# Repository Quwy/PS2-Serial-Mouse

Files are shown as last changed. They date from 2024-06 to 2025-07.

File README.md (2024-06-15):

# PS/2 to Serial mouse adapter
Active adapter for connect PS/2 mouse to the RS232C serial port.

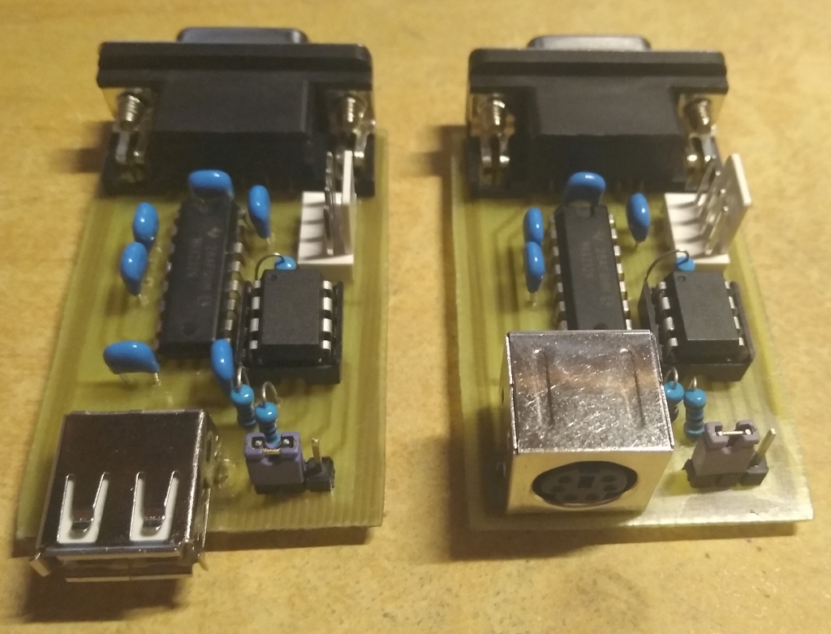
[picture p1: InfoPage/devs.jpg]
Adapters photo


With this adapter you don't need to search and buy rare and expensive old serial mouse for your retro computer. Any mouse with PS/2 interface and most of simple USB-mouses will operate as Microsoft or Logitech serial mouse.

* Only 16 parts including PCB and sockets.
* Small device size.
* Simple one-layer one-side PCB.
* No SMD components.
* Common and cheap microcontroller.
* Selectable 3-button mouse protocol (Microsoft or Logitech).
* Open-source electronics and firmware.

Adapter is based on ATtiny25 microcontroller, but PCB layout and firmware source are fully compatible with whole 25/45/85 series without any changes.

There are two variants of PCB layout: with PS/2 and USB mouse socket. Both they have one-layer one-side design without VIA covering and fully ready even for manual tracing.

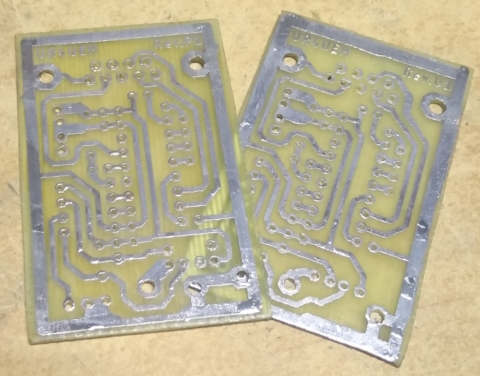
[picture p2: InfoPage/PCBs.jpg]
PCBs


They are fully identical except an mouse socket type.

Note what USB version does not provide true USB host. The USB socket is only used as built-in PS/2-to-USB passive adapter.

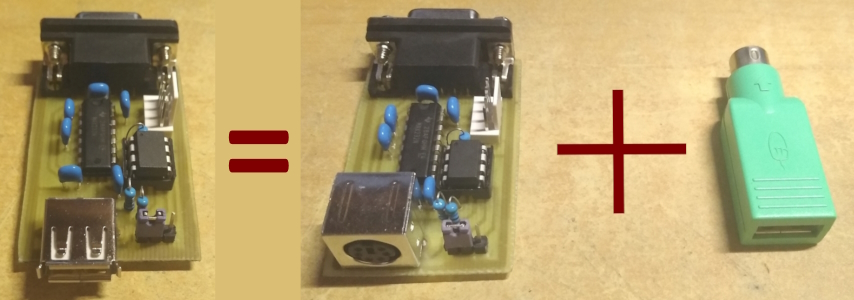
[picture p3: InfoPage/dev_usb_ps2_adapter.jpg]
USB Adapter


Only universal USB+PS/2 mouse will work!

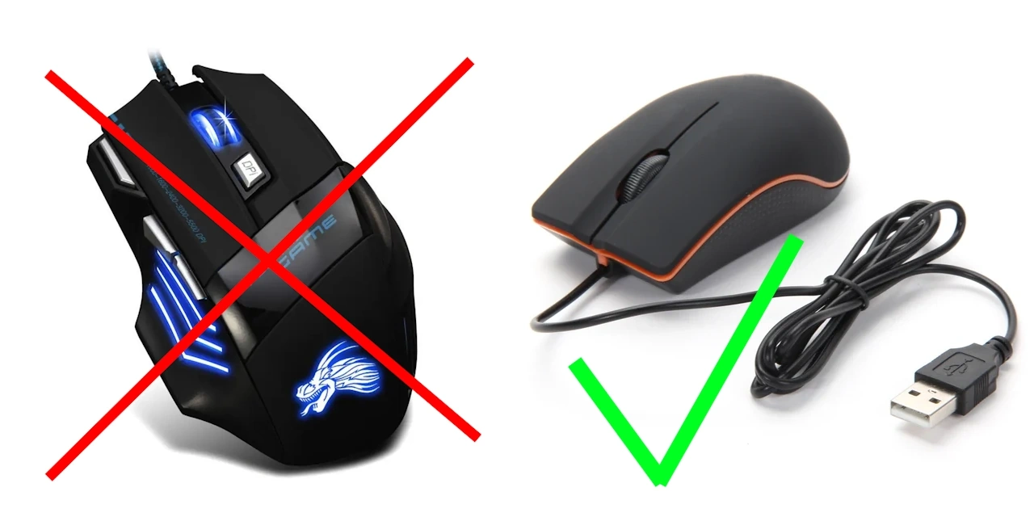
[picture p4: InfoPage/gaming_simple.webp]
Gaming VS Simple


Usually it is a simple office mouse with two buttons and one clickable wheel.

Jumper is used to switch 3-button mouse protocol extensions between Microsoft and Logitech style. The 1-2 position (close to the mouse socket) mean Microsoft, 2-3 respectively Logitech. Jumper is hotplug-ready.

Since RS232C port does not provide power supply enough to feed most of PS/2 mouses, the standart "floppy-style" 4-pin MOLEX plug is used as power source (+5V line only).

Please see also [README of schematic diagramm](https://github.com/Quwy/PS2-Serial-Mouse/blob/main/Electronix/README.md) and [README of firmware section](https://github.com/Quwy/PS2-Serial-Mouse/blob/main/Firmware/README.md).

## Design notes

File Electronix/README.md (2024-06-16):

# PS2 to Serial mouse adapter electronics

Schematic diagrams and PCB layouts for both PS/2 and USB adapter variants.

## PS/2 socket

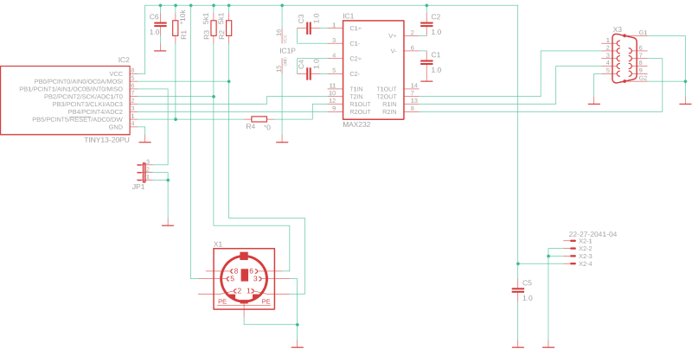
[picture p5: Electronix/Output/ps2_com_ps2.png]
PS/2 Diagramm


## USB socket

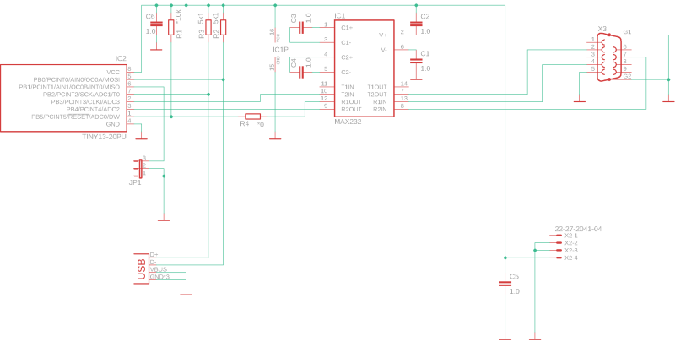
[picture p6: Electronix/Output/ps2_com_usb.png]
USB Diagramm


## Differences between RTS-only and RTS+DTR implementations.

**RTS-only** implementation listen only RTS line of the RS232C port to detect init/reset signal from the mouse driver. The DTR line is ignored. This mean not full compliance with Serial Mouse specs, but enough for most existing mouse drivers. But it does give an opportunity to preserve pin 1 of microcontroller as default RESET function and use simple and cheap ISP programmers (such as [USBASP](https://www.google.com/search?q=usbasp)) to flash IC.

In this mode resistor R4 must **NOT** be installed on PCB, and there is recommended to install resistor R1 as RESET pull-up.

**RTS+DTR** implementation as opposed to RTS-only listen both RTS and DTR signals and will compatible with any mouse driver. But this is achieved at the cost of switching pin 1 to GPIO mode and lose microcontroller's ISP function. Since fuses will flashed, only high voltage serial programming tool can be used to write the IC (including reset fuses to default state). So be very careful with fuses for RTS-DTR mode.

For RTS+DTR mode resistor R4 (0-10 Ohm or jumper wire) must be installed to PCB and R1 must **NOT** be installed.

Everything else is same in both modes.

## PCB layout features

In the both PS/2 and USB layouts socket shield is used as signal ground trace for connect mouse GND pin to adapter ground. For this reason only metal sockets must be used. Especially it concerns a PS/2 which wide available in the whole-plastic variant without an metal shield.

## PCB renders and Gerber files
https://github.com/Quwy/PS2-Serial-Mouse/tree/main/Electronix/Output

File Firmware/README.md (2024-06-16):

# PS2 to Serial mouse adapter Firmware

This folder contain Firmware sources for the adapter.

To build please use Microchip Studio 7.0 or later with AVR/GNU C Compiler 7.3.0 or more modern. Previous versions of compiler can reach microcontroller's flash size.

Please see [Defines.h](https://github.com/Quwy/PS2-Serial-Mouse/blob/main/Firmware/Defines.h) file for build options before make.

## FUSES

About differences between RTS-only and RTS+DTR implementations please see [electronics section](https://github.com/Quwy/PS2-Serial-Mouse/blob/main/Electronix/README.md).

### RTS-only fuses
```
efuse 0x01
lfuse 0xc1
hfuse 0xdf
```

### RTS+DTR fuses
```
efuse 0x01
lfuse 0xc1
hfuse 0x7f
```

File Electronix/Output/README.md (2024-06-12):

# PS2 to Serial mouse adapter PCB renders

Folder for PCB prerenders and Gerber files

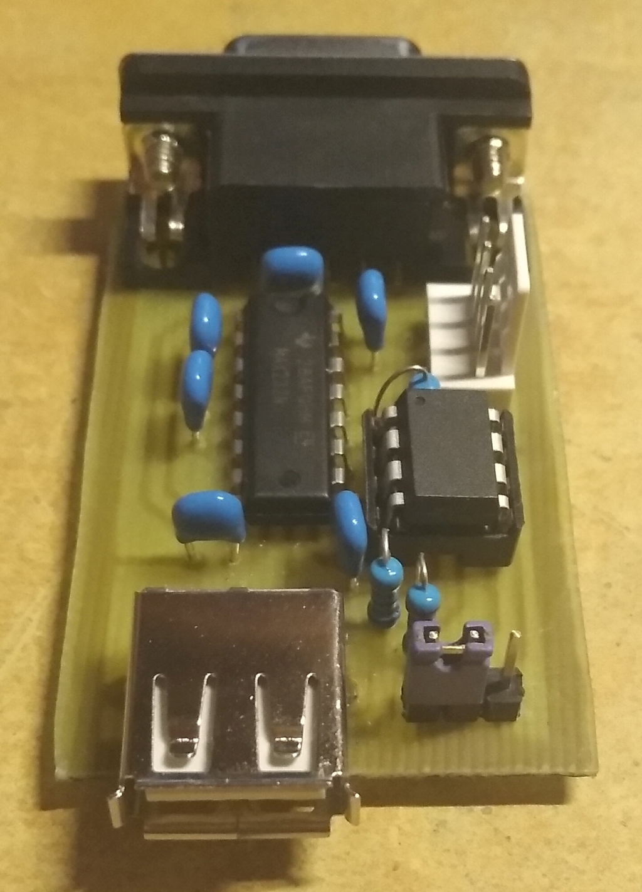
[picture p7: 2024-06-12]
InfoPage/dev_usb.jpg

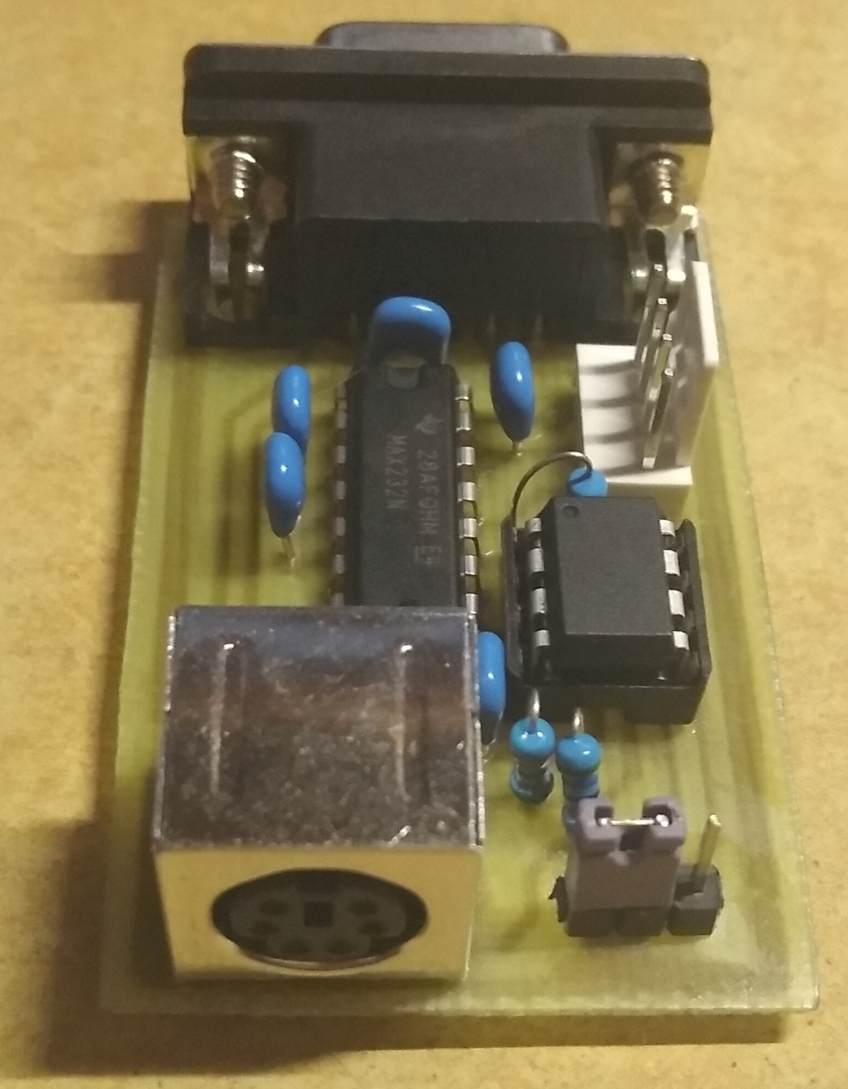
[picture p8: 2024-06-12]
InfoPage/dev_ps2.jpg

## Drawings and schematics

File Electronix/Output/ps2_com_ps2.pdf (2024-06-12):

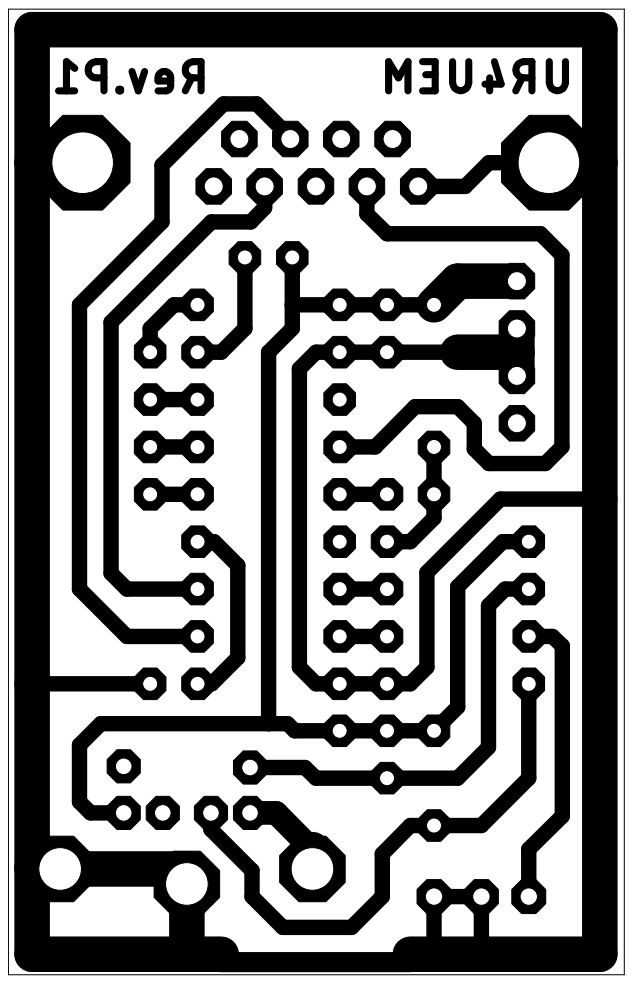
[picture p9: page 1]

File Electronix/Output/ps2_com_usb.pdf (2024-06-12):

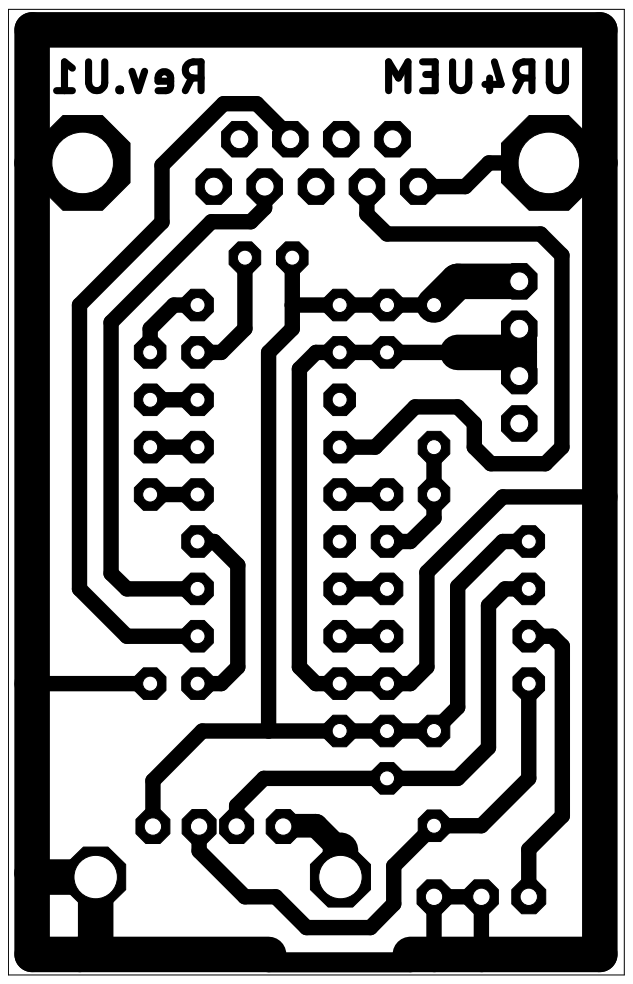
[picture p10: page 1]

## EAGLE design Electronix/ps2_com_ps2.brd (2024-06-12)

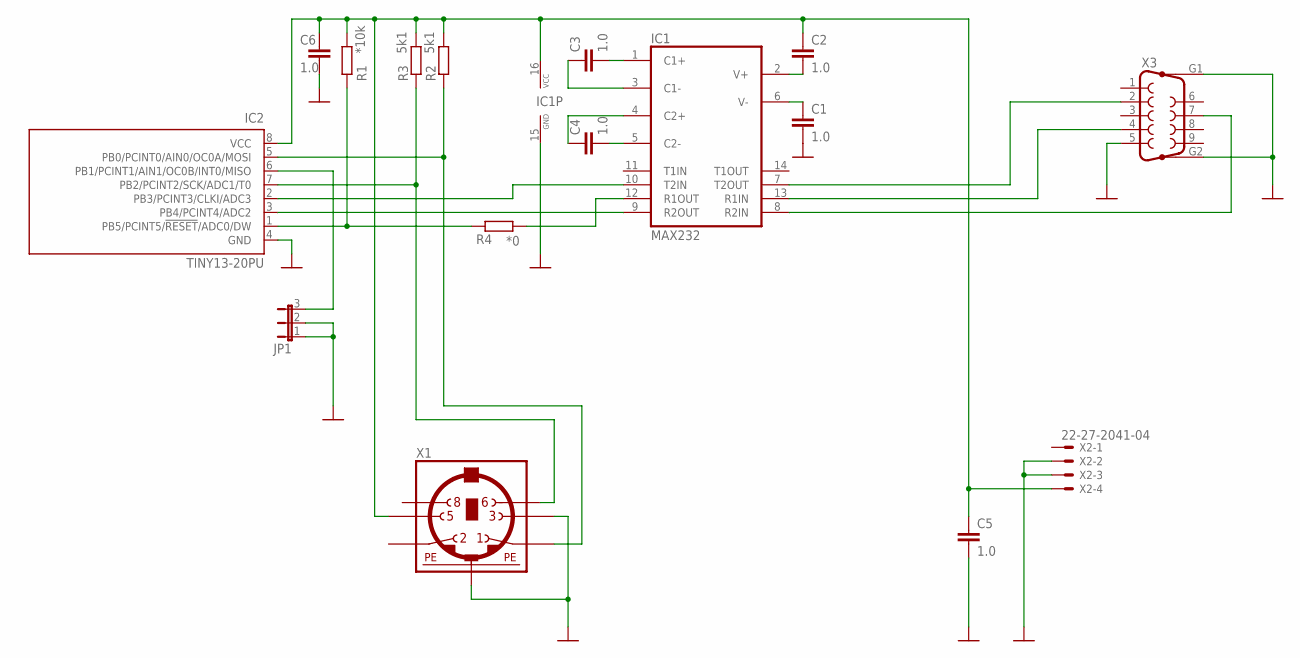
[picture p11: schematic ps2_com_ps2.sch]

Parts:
C1, C2, C3, C4, C5, C6: 1.0; C025-025X050
IC1: MAX232; DIL16
IC2: TINY13-20PU; DIL08
JP1: JP2E; JP2
R1: *10k; 0204/7
R2: 5k1; 0204/5
R3: 5k1; 0204V
R4: *0; 0204V
X1: MINI_DIN_6; M_DIN6
X2: 22-27-2041-04; 6410-04
X3: F09HP

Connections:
CLOCK: IC2.7 (PB2/PCINT2/SCK/ADC1/T0), R3.1, X1.6
DATA: IC2.5 (PB0/PCINT0/AIN0/OC0A/MOSI), R2.1, X1.1
DTR: IC1.13 (R1IN), X3.4
GND: C1.2, C5.2, C6.2, IC1.15 (GND), IC2.4 (GND), JP1.1, JP1.2, X1.3, X1.SH1 (PE1), X1.SH2 (PE1), X1.SH3 (PE1), X2.2, X2.3, X3.5, X3.G1, X3.G2
unnamed: C4.2, IC1.5 (C2-)
unnamed: C4.1, IC1.4 (C2+)
unnamed: C3.1, IC1.3 (C1-)
unnamed: C3.2, IC1.1 (C1+)
unnamed: C1.1, IC1.6 (V-)
unnamed: C2.2, IC1.2 (V+)
unnamed: IC2.6 (PB1/PCINT1/AIN1/OC0B/INT0/MISO), JP1.3
unnamed: IC1.12 (R1OUT), R4.1
RTS: IC1.8 (R2IN), X3.7
RXD: IC1.7 (T2OUT), X3.2
TTL_DTR: IC2.1 (PB5/PCINT5/!RESET!/ADC0/DW), R1.1, R4.2
TTL_RTS: IC1.9 (R2OUT), IC2.3 (PB4/PCINT4/ADC2)
TTL_RXD: IC1.10 (T2IN), IC2.2 (PB3/PCINT3/CLKI/ADC3)
VCC: C2.1, C5.1, C6.1, IC1.16 (VCC), IC2.8 (VCC), R1.2, R2.2, R3.2, X1.5, X2.4

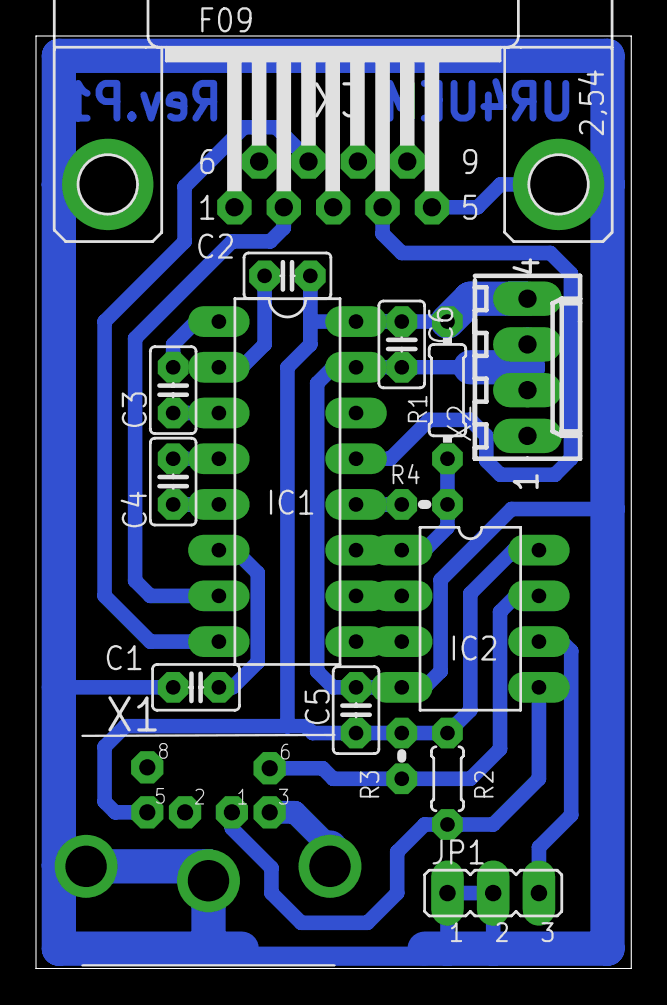
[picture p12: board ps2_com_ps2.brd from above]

Board: 2 copper layers, 33.1 x 51.8 mm, 16 parts (0 on the bottom side), 18 nets.

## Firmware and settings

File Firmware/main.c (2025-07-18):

/*
 * main.c
 *
 * Main module
 * 
 * Author: Mike Cherkes, UR4UEM
 *
 */ 

#include "Defines.h"

#include <avr/io.h>
#include <avr/interrupt.h>
#include <avr/sleep.h>
#include <avr/wdt.h>
#include <stdint.h>
#include <stdbool.h>

#if defined(START_MARKER)
#include <util/delay.h>
#endif

#include "PS2_mouse.h"
#include "UART_mouse.h"

#define INITIAL_PINB ((1 << PB0) | (1 << PB2) | (1 << PB4)) // initial state of pins on PORTB (initial value assumes high levels on the SDA ans SCL as bus idle state, high on RTS as no terminal connected)

typedef enum {
    TERMINAL_STATE_INACTIVE,
    TERMINAL_STATE_PENDING,
    TERMINAL_STATE_ACTIVE
} terminal_state_t;

static volatile terminal_state_t terminal_state;
static volatile bool terminal_tx_ext_id = false;

// init watchdog
static inline void wdt_init(void) {
    WDTCR = (1 << WDCE) | (1 << WDE); // watchdog preparing
    WDTCR = (1 << WDIE) | WDTO_60MS; // setup watchdog to interrupt mode every 60 ms
}

// init GPIO system
static inline void gpio_init(void) {
    
    #ifdef START_MARKER // start marker for logic analizer trigger
    DDRB |= (1 << DDB3);
    _delay_us(10);
    DDRB &= ~(1 << DDB3);
    #endif

    GIMSK |= (1 << PCIE); // Enable pin changes interrupt
}

// init MCU
static inline void mcu_init(void) {
    sleep_enable(); // prepare sleep mode
    set_sleep_mode(SLEEP_MODE_IDLE); // SLEEP_MODE_IDLE allows to handle all necessary events
    sei(); // enable interrupts

    #ifdef PROTEUS // Proteus incorrectly simulates PLL clock (set 64 MHz instead of 16 MHz)
    CLKPR |= (1 << CLKPCE); // enable system clock prescaler
    CLKPR = (1 << CLKPS1);  // set prescaler for /4
    #endif
}

// pin change event local handler
static inline void main_PCINT0(const uint8_t prev_PINB) {
    if(uart_host_active(prev_PINB) && !uart_host_active(PINB)) { // if terminal ready pins changed state from "ready" to "not ready"
        switch(terminal_state) {
            case TERMINAL_STATE_ACTIVE: // if terminal was active, stopping all and deactivate terminal state
                uart_mouse_stop();
                ps2_mouse_stop(); // reset mouse and stop PS2 communication
                terminal_tx_ext_id = false;
                terminal_state = TERMINAL_STATE_INACTIVE;
                break;

            case TERMINAL_STATE_PENDING: // if terminal in pending state, just reset state to inactive
                terminal_state = TERMINAL_STATE_INACTIVE;
                break;

            default: // nothing to do if terminal already inactive
                break;
        }
    }
}

// perform periodic checks and tasks
static inline void main_timer_process(void) {
    switch(terminal_state) {
        case TERMINAL_STATE_PENDING: // if terminal state remains pending whole WDT timer delay, set terminal ready state
            terminal_state = TERMINAL_STATE_ACTIVE;
            ps2_mouse_start(); // init PS/2 mouse and start communication
            break;

        case TERMINAL_STATE_INACTIVE: // if terminal state is inactive
            if(uart_host_active(PINB)) { // check pins
                terminal_state = TERMINAL_STATE_PENDING; // set sdtate to pending if pins in the active state
            }
            break;

        default: // if terminal is active or unknown state, do nothing
            break;
    }

    if(terminal_tx_ext_id && terminal_state == TERMINAL_STATE_ACTIVE) {
        uart_mouse_tx_ext_id(); // send extended id if terminal is active and primary id already sent
        terminal_tx_ext_id = false;
    }
}


// main function
int main(void) {
    const ps2_mouse_state_t *ps2_mouse_state;
    
    gpio_init();
    mcu_init();
    uart_mouse_init();
    ps2_mouse_init(&ps2_mouse_state); // init PS2 mouse and get mouse data pointer
    wdt_init();
    
    #ifndef DUMMY_TEST_MODE

    terminal_state = (uart_host_active(PINB) ? TERMINAL_STATE_PENDING : TERMINAL_STATE_INACTIVE); // initial terminal state

    // main event loop
    while(true) {
        sleep_cpu(); // always try to avoid free-running main loop, use sleep mode if no current tasks

        ps2_mouse_process(terminal_state != TERMINAL_STATE_ACTIVE); // process mouse events if PC terminal is active
        
        if(ps2_mouse_responce_ok()) { // if init mouse response is "OK"
            uart_mouse_tx_id(); // send primary mouse id to port
            terminal_tx_ext_id = true; // reload external id send flag
        }

        if(ps2_mouse_was_updated()) { // if mouse data updated
            uart_mouse_tx_event(ps2_mouse_state->DX, ps2_mouse_state->DY, ps2_mouse_state->left, ps2_mouse_state->right, ps2_mouse_state->middle); // sent UART packet with ioncoming data
        }
    }

    #else

    #ifndef UART_HI_BPS
    ps2_tx(0xF3); // set report rate
    ps2_tx(20); // in 1200 bps mode only 20 reports per second fit into UART bandwidth
    #endif

    ps2_tx(0xF4); // start auto reporting

    // main event loop
    while(true) {
        sleep_cpu();

        // repeat all PS/2 outgoing data to the UART
        while(ps2_rx_count() > 0) {
            uart_tx(ps2_rx());
        }
    }

    #endif
}

// pin change interrupt handler (general for all modules)
ISR(PCINT0_vect) {
    static uint8_t prev_PINB = INITIAL_PINB;

    GIFR |= (1 << PCIF); // clear interrupt flag

    ps2_PCINT0(prev_PINB); // call PS/2 pin change handler
    main_PCINT0(prev_PINB); // call main pin change handler

    prev_PINB = PINB; // save prior port state
}

// watchdog interrupt handler
ISR(WDT_vect) {
    WDTCR |= (1 << WDIE); // important to renew WDIE bit in each call (reset will performed if no WDIE bit at next watchdog "tick")

    #ifndef DUMMY_TEST_MODE
    main_timer_process(); // UART scheduled events dispatcher
    #endif
}

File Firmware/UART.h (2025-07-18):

/*
 * UART.h
 *
 * UART simplified (TX-only) driver
 * 
 * Author: Mike Cherkes, UR4UEM
 *
 */ 

#ifndef UART_H_
#define UART_H_

#include <avr/interrupt.h>
#include <avr/io.h>
#include <stdint.h>
#include <stdbool.h>

#include "Defines.h"
#include "BufProc.h"

#define UART_TX_BUFFER_SIZE (4 * 3) // 3 packets of 3-button mouse or 4 packets of 2-button mouse

#ifdef UART_HI_BPS
  #ifndef UART_19200_BPS
    #define UART_BPS_CORRECTION (-1) // measured on the real hardware
  #else
    #define UART_BPS_CORRECTION (-2) // measured on the real hardware
  #endif
#else
  #define UART_BPS_CORRECTION (+8) // measured on the real hardware
#endif

typedef enum {
    UART_STAGE_IDLE,
    UART_STAGE_TX_START_BIT,
    UART_STAGE_TX_DATA,
    UART_STAGE_TX_STOP_BIT,
    UART_STAGE_TX_FINISH // second stop bit (as recommended)
} uart_stage_t;

static volatile uint8_t uart_current_byte; // current transmitted byte
static volatile uint8_t uart_current_bit; // current transmitted bit
static volatile uint8_t uart_tx_buffer[UART_TX_BUFFER_SIZE]; // TX buffer
static volatile uint8_t uart_tx_buffer_size = 0; // actual size of TX data
static volatile uart_stage_t uart_stage = UART_STAGE_IDLE; // protocol stage

static inline void uart_init(void) {
    // Pins init
    PORTB &= ~(1 << PB4); // disable pull-up for pin 3 (PB4/RTS)
    DDRB &= ~(1 << DDB4); // set pin 3 (PB4/RTS) as input
    #ifdef RESET_AS_DTR
    PORTB &= ~(1 << PB5); // disable pull-up for pin 1 (PB5/DTR)
    DDRB &= ~(1 << DDB5); // set pin 1 (PB5/DTR) as input
    #endif
    PORTB |= (1 << PB3); // set pin 2 (PB3/RXD) to "high" idle state
    DDRB |= (1 << DDB3); // set pin 2 (PB3/RXD) as output

    // Timer0 init
    TCCR0A |= (1 << WGM01); // set Timer0 CTC mode: top value is OCR0A
    TIMSK |= (1 << OCIE0A); // enable compare match interrupt with OCR0A (TIMER0_COMPA_vect)

    // Interrupts init
    PCMSK |= (1 << PCINT4); // enable pin 3 (PB4/RTS) change interrupt
    #ifdef RESET_AS_DTR
    PCMSK |= (1 << PCINT5); // enable pin 1 (PB5/RESET/DTR) change interrupt
    #endif
}

// start UART timer
static void uart_start_timer(void) {
    TCNT0 = 0; // reset timer counter
    #ifdef UART_HI_BPS
    #ifndef UART_19200_BPS
    OCR0A = 208 + UART_BPS_CORRECTION; // set top value for 9600 bps (2 000 000 / 9 600) = 208 (plus correction from the real device sample)
    #else
    OCR0A = 104 + UART_BPS_CORRECTION; // set top value for 19200 bps (2 000 000 / 19200) = 104 (plus correction from the real device sample)
    #endif
    TCCR0B |= (1 << CS01); // start timer with prescaler /8 (16 000 000 / 8 = 2 000 000 increments/sec)
    #else
    OCR0A = 208 + UART_BPS_CORRECTION; // set top value for 1200 bps (250 000 / 1200) = 208 (plus correction from the real device sample)
    TCCR0B |= (1 << CS00) | (1 << CS01); // start timer with prescaler /64 (16 000 000 / 64 = 250 000 increments/sec)
    #endif
}

// stop UART timer
static void uart_stop_timer(void) {
    TCCR0B &= ~(1 << CS00) & ~(1 << CS01) & ~(1 << CS02); // stop timer clock
}

// check for PC ready to communicate with mouse
static inline bool uart_host_active(const uint8_t PORT) {
    #ifdef RESET_AS_DTR
    return ((PORT & ((1 << PB4) | (1 << PB5))) == 0); // check for "low" on pins 3 (PB4/RTS), 1 (PB5/RESET/DTR), equialent of ((PORT & (1 << PB4)) == 0) && ((PORT & (1 << PB5)) == 0)
    #else
    return ((PORT & (1 << PB4)) == 0); // check for "low" on pin 3 (PB4/RTS)
    #endif
}

// start transmitting
static void uart_start_byte_tx() {
    if(uart_stage == UART_STAGE_IDLE && uart_host_active(PINB)) { // start TX only if idle and PC terminal is active
        uart_stage = UART_STAGE_TX_START_BIT; // first stage to form TX start condition
        uart_current_byte = buf_get_byte(uart_tx_buffer, &uart_tx_buffer_size); // extract next byte from TX buffer
        uart_current_bit = 0; // low bit first
        uart_start_timer(); // start transmitting
    }
}

// interface function to transmit a byte
static void uart_tx(const uint8_t byte) {
    buf_set_byte(byte, uart_tx_buffer, &uart_tx_buffer_size, UART_TX_BUFFER_SIZE); // extract next byte from buffer
    uart_start_byte_tx(); // start transmitting
}

// set state of TX data line
static void uart_set_tx(const bool state) {
    if(state) {
        PORTB |= (1 << PB3); // pin 2 (PB3/TX) to "high"
    } else {
        PORTB &= ~(1 << PB3); // pin 2 (PB3/TX) to "low"
    }
}

// check for bytes in the buffer and start TX if any
static void uart_process_tx(void) {
    if(uart_tx_buffer_size > 0) { // if buffer not empty
        uart_start_byte_tx();
    }
}

// abort any transmitting and clear buffers (usually if terminal becomes inactive)
static void uart_abort(void) {
    uart_stage = UART_STAGE_IDLE; // transmission aborted
    uart_stop_timer(); // stop UART clock timer
    uart_set_tx(true); // set TX line idle state
    uart_tx_buffer_size = 0; // clear TX buffer
}

// check for available space in the TX buffer
static inline uint8_t uart_tx_room(void) {
    return UART_TX_BUFFER_SIZE - uart_tx_buffer_size;
}

// UART clock timer handler
ISR(TIMER0_COMPA_vect) {
    switch(uart_stage) {
        case UART_STAGE_TX_START_BIT: // generate start bit delay
            uart_stage = UART_STAGE_TX_DATA; // next stage after delay finished
            uart_set_tx(false); // start bit always "low"
            break;

        case UART_STAGE_TX_DATA: // data stage
            uart_set_tx((uart_current_byte & (1 << uart_current_bit)) != 0); // set TX line according to current bit
            if(++uart_current_bit == 7) { // if last (7-th) bit was populated on TX line
                uart_stage = UART_STAGE_TX_STOP_BIT; // set next stage
            }
            break;

        case UART_STAGE_TX_STOP_BIT: // generate first stop bit delay
            uart_stage = UART_STAGE_TX_FINISH; // set next stage
            uart_set_tx(true); // stop bit always "high"
            break;

        case UART_STAGE_TX_FINISH: // second stop bit finished
        default: // if any unexpected state passed
            uart_stage = UART_STAGE_IDLE; // transmission finished
            uart_set_tx(true); // set TX line idle state
            uart_stop_timer(); // stop UART clock timer
            uart_process_tx(); // check buffer for next byte and start transmitting if any
    }
}

#endif /* UART_H_ */
